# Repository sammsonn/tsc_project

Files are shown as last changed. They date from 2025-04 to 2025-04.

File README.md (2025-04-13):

# Nume: Samson Alexandru-Valentin
# Grupa: 332CC

## 1. Descriere Generala:
Acest repository contine fisierele de design hardware pentru proiectul OpenBook, un e-book reader ieftin si open source, generate in cadrul fazei EVT. Obiectivul acestei faze a fost transformarea specificatiilor de sistem intr-un design hardware functional si integrat mecanic, pregatit pentru fabricarea primelor prototipuri.

## Etapele Initiale ale Dezvoltarii EVT (Rezumat)

Dezvoltarea designului livrat aici a urmat cativa pasi cheie:

1.  **Clarificarea Specificatiilor si Planificarea:** Am inceput prin analiza detaliata a specificatiilor primite de la Arhitectul de Sistem pentru a intelege complet cerintele functionale, de performanta si de cost. Am adresat intrebari pentru clarificarea oricaror ambiguitati si am stabilit un plan de lucru initial. Tot in aceasta etapa am configurat mediul de dezvoltare in Fusion si repository-ul Git.

2.  **Selectia Componentelor si Crearea Librariilor:** Pe baza specificatiilor, am selectat componentele electronice specifice (Part Numbers), acordand o atentie deosebita costului, disponibilitatii pe termen lung si performantei. Pentru fiecare componenta aleasa, am creat sau validat librariile necesare in Fusion 360: simbolul schematic, footprint-ul PCB (conform datasheet) si, unde a fost posibil, modelul 3D asociat. Am inceput compilarea unui Bill of Materials (BOM) preliminar.

3.  **Captura Schematica (Schematic Capture):** Folosind librariile create, am desenat diagrama schematica in Fusion 360. Aceasta reprezinta conexiunile logice dintre toate componentele electronice. Am structurat schema pe module functionale (ex: Alimentare, Procesor, Memorie, Interfata Display, etc.) pentru claritate si am rulat verificari ERC (Electrical Rule Check) pentru a detecta erori de baza.

4.  **Proiectarea PCB (PCB Layout) - Faza Initiala:** Am inceput transpunerea schemei intr-un layout fizic pe placa de circuit imprimat (PCB). Aceasta a inclus definirea conturului placii (conform dimensiunilor impuse de carcasa), definirea structurii straturilor (layer stackup) si plasarea initiala a componentelor critice (conectori, circuite integrate principale, componente cu constrangeri mecanice), tinand cont de fluxul de semnal si constrangerile carcasei.

5.  **Modelare 3D si Integrare Mecanica Preliminara:** in paralel cu layout-ul PCB, am creat modele 3D simplificate, dar dimensional corecte, pentru elementele non-PCB majore (Display E-Ink, Baterie LiPo). Am inceput asamblarea virtuala in Fusion, combinand modelul 3D al PCB-ului (cu componentele plasate), modelele display-ului si bateriei, si modelul 3D al carcasei (primit) pentru a verifica potrivirea generala si a identifica potentiale conflicte de spatiu.

## 2. Diagrama Bloc
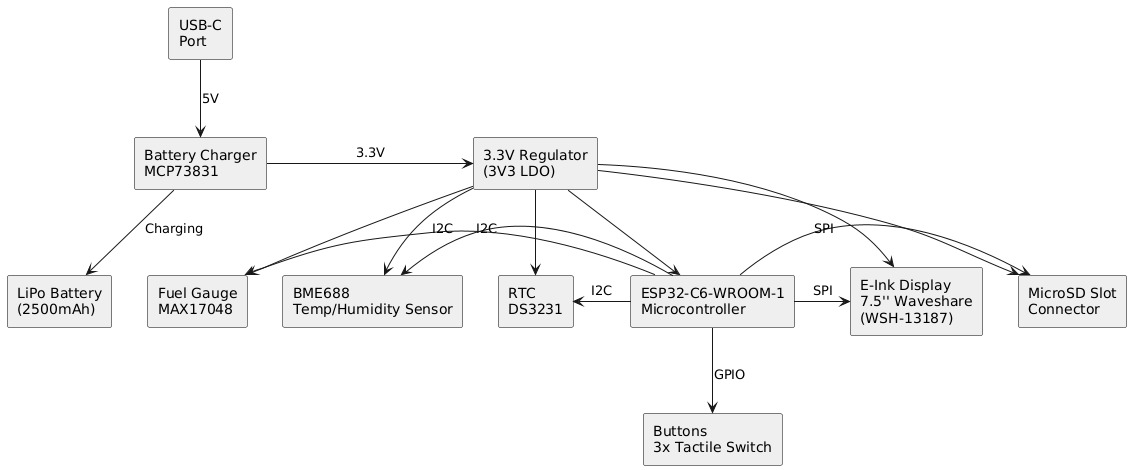
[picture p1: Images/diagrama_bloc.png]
Diagrama


## 3. BOM - Bill of Materials
| Device | Value | Check_Price | Datasheet |
|---|---|---|---|
| ADAFRUIT_LEDCHIP-LED0603 | - | [Link](https://www.snapeda.com/parts/KP-1608SURCK/Kingbright/view-part/?ref=search&t=LED%200603) | [Link](https://www.snapeda.com/parts/KP-1608SURCK/Kingbright/datasheet/) |
| SJ | - | [Link](https://grabcad.com/library/solder-jumpers-1) | [Link](https://grabcad.com/library/solder-jumpers-1) |
| EAGLE-LTSPICE_C | 0.1uF/50V | [Link](https://componentsearchengine.com/part-view/CC0402MRX5R5BB106/YAGEO) | [Link](https://componentsearchengine.com/Datasheets/2/CC0402MRX5R5BB106.pdf) |
| ESP32_WROVER_EAGLE-LTSPICE_R | 0.47 | [Link](https://componentsearchengine.com/part-view/R0402%201%25%20100%20K%20(RC0402FR-07100KL)/YAGEO) | [Link](https://www.yageo.com/upload/media/product/products/datasheet/rchip/PYu-RC_Group_51_RoHS_L_12.pdf) |
| ESP32_WROVER_EAGLE-LTSPICE_R | 100K | [Link](https://componentsearchengine.com/part-view/R0402%201%25%20100%20K%20(RC0402FR-07100KL)/YAGEO) | [Link](https://www.yageo.com/upload/media/product/products/datasheet/rchip/PYu-RC_Group_51_RoHS_L_12.pdf) |
| EAGLE-LTSPICE_C | 100nF | [Link](https://componentsearchengine.com/part-view/CC0402MRX5R5BB106/YAGEO) | [Link](https://componentsearchengine.com/Datasheets/2/CC0402MRX5R5BB106.pdf) |
| RCL_CPOL-EUCT3528 | 100uF TANT | [Link](https://www.snapeda.com/parts/TAJB475K025RNJ/AVX/view-part/?ref=dk&t=capacitor%203528&con_ref=None) | [Link](https://s3.amazonaws.com/snapeda/datasheet/TAJB475K025RNJ_AVX.pdf) |
| ESP32_WROVER_EAGLE-LTSPICE_R | 10K | [Link](https://componentsearchengine.com/part-view/R0402%201%25%20100%20K%20(RC0402FR-07100KL)/YAGEO) | [Link](https://www.yageo.com/upload/media/product/products/datasheet/rchip/PYu-RC_Group_51_RoHS_L_12.pdf) |
| EAGLE-LTSPICE_C | 10uF | [Link](https://componentsearchengine.com/part-view/CC0402MRX5R5BB106/YAGEO) | [Link](https://componentsearchengine.com/Datasheets/2/CC0402MRX5R5BB106.pdf) |
| 112A-TAAR-R03_ATTEND | 112A-TAAR-R03_ATTEND | [Link](https://store.comet.srl.ro/Catalogue/Product/43497/) | [Link](https://store.comet.bg/download-file.php?id=8824) |
| ESP32_WROVER_EAGLE-LTSPICE_R | 15 | [Link](https://componentsearchengine.com/part-view/R0402%201%25%20100%20K%20(RC0402FR-07100KL)/YAGEO) | [Link](https://www.yageo.com/upload/media/product/products/datasheet/rchip/PYu-RC_Group_51_RoHS_L_12.pdf) |
| EAGLE-LTSPICE_C | 1uF | [Link](https://componentsearchengine.com/part-view/CC0402MRX5R5BB106/YAGEO) | [Link](https://componentsearchengine.com/Datasheets/2/CC0402MRX5R5BB106.pdf) |
| EAGLE-LTSPICE_C | 1uF/50V | [Link](https://componentsearchengine.com/part-view/CC0402MRX5R5BB106/YAGEO) | [Link](https://componentsearchengine.com/Datasheets/2/CC0402MRX5R5BB106.pdf) |
| ESP32_WROVER_EAGLE-LTSPICE_R | 2.2 | [Link](https://componentsearchengine.com/part-view/R0402%201%25%20100%20K%20(RC0402FR-07100KL)/YAGEO) | [Link](https://www.yageo.com/upload/media/product/products/datasheet/rchip/PYu-RC_Group_51_RoHS_L_12.pdf) |
| ESP32_WROVER_EAGLE-LTSPICE_R | 200 | [Link](https://componentsearchengine.com/part-view/R0402%201%25%20100%20K%20(RC0402FR-07100KL)/YAGEO) | [Link](https://www.yageo.com/upload/media/product/products/datasheet/rchip/PYu-RC_Group_51_RoHS_L_12.pdf) |
| ESP32_WROVER_SPARKFUN-DISCRETESEMI_MOSFET_PCH-DMG2305UX-7 | 20V/4.2A/52m?/1.4W | [Link](https://componentsearchengine.com/part-view/DMG2305UX-7/Diodes%20Incorporated) | [Link](https://www.diodes.com//assets/Datasheets/DMG2305UX.pdf) |
| ESP32_WROVER_EAGLE-LTSPICE_R | 2K | [Link](https://componentsearchengine.com/part-view/R0402%201%25%20100%20K%20(RC0402FR-07100KL)/YAGEO) | [Link](https://www.yageo.com/upload/media/product/products/datasheet/rchip/PYu-RC_Group_51_RoHS_L_12.pdf) |
| EAGLE-LTSPICE_C | 4.7uF | [Link](https://componentsearchengine.com/part-view/CC0402MRX5R5BB106/YAGEO) | [Link](https://componentsearchengine.com/Datasheets/2/CC0402MRX5R5BB106.pdf) |
| EAGLE-LTSPICE_C | 4.7uF/25V | [Link](https://componentsearchengine.com/part-view/CC0402MRX5R5BB106/YAGEO) | [Link](https://componentsearchengine.com/Datasheets/2/CC0402MRX5R5BB106.pdf) |
| ESP32_WROVER_EAGLE-LTSPICE_R | 5k1 | [Link](https://componentsearchengine.com/part-view/R0402%201%25%20100%20K%20(RC0402FR-07100KL)/YAGEO) | [Link](https://www.yageo.com/upload/media/product/products/datasheet/rchip/PYu-RC_Group_51_RoHS_L_12.pdf) |
| 744043680IND_4828-WE-TPC_WRE | 68uH | [Link](https://ro.mouser.com/ProductDetail/Wurth-Elektronik/744043680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.) | [Link](https://www.we-online.com/components/products/datasheet/744043680.pdf) |
| BD5229G-TR | BD5229G-TR | [Link](https://componentsearchengine.com/part-view/BD5229G-TR/ROHM%20Semiconductor) | [Link](https://datasheet.datasheetarchive.com/originals/distributors/Datasheets_SAMA/f2b9741ef86007909f138d561a359946.pdf) |
| ESP32_WROVER_BME680_BME680 | BME688 | [Link](https://www.snapeda.com/parts/BME680/Bosch/view-part/?welcome=home) | [Link](https://www.snapeda.com/parts/BME680/Bosch%20Sensortec/datasheet/) |
| BUTTON_CUSYOMV1V2 | BUTTON_CUSYOMV1V2 | [Link](https://industry.panasonic.com/global/en/products/control/switch/light-touch/number/evqpuj02k) | [Link](https://industry.panasonic.com/global/en/downloads?tab=catalog&small_g_cd=203&part_no=EVQPUJ02K) |
| CPH3225A | CPH3225A | [Link](https://www.snapeda.com/parts/CPH3225A/Seiko+Instruments/view-part/?ref=eda) | [Link](https://www.snapeda.com/parts/CPH3225A/Seiko+Instruments/view-part/?ref=eda ) |
| DS3231SN# | DS3231SN# | [Link](https://www.snapeda.com/parts/DS3231SN%23/Analog+Devices/view-part/?ref=eda) | [Link](https://www.snapeda.com/parts/DS3231SN%23/Analog+Devices/view-part/?ref=eda) |
| ESP32-C6-WROOM-1-N8 | ESP32-C6-WROOM-1-N8 | [Link](https://www.snapeda.com/parts/ESP32-C6-WROOM-1-N8/Espressif+Systems/view-part/?ref=eda) | [Link](https://www.snapeda.com/parts/ESP32-C6-WROOM-1-N8/Espressif+Systems/view-part/?ref=eda) |
| ESP32C6_VARISTORCN1812 | ESP32C6_VARISTORCN1812 | [Link](https://www.mouser.co.uk/ProductDetail/EPCOS-TDK/B72520T0350K062?qs=dEfas%2FXlABIszF52uu7vrg%3D%3D) | [Link](https://www.tdk-electronics.tdk.com/inf/75/db/CTVS_14/Surge_protection_series.pdf) |
| ESP32_WROVER_SPARKFUN-IC-POWER_MCP73831 | ESP32_WROVER_SPARKFUN-IC-POWER_MCP73831 | [Link](https://ro.mouser.com/ProductDetail/Microchip-Technology/MCP73831T-2ACI-OT?qs=yUQqVecv4qvbBQBGbHx0Mw%3D%3D) | [Link](https://ro.mouser.com/datasheet/2/268/MCP73831_Family_Data_Sheet_DS20001984H-3441711.pdf) |
| FH34SRJ-24S-0.5SH_99_ | FH34SRJ-24S-0.5SH_99_ | [Link](https://componentsearchengine.com/part-view/FH34SRJ-24S-0.5SH(99)/Hirose) | [Link](https://www.hirose.com/en/product/document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) |
| MAX17048G+T10 | MAX17048G+T10 | [Link](https://www.snapeda.com/parts/MAX17048G+T10/Analog+Devices/view-part/?ref=eda) | [Link](https://www.snapeda.com/parts/MAX17048G+T10/Analog+Devices/view-part/?ref=eda) |
| MBR0530. | MBR0530. | [Link](https://www.snapeda.com/parts/MBR0530/Onsemi/view-part/?ref=eda) | [Link](https://www.snapeda.com/parts/MBR0530/ON%20Semiconductor/datasheet/) |
| PGB1010603MR. | PGB1010603MR. | [Link](https://www.snapeda.com/parts/PGB1010603MR/Littelfuse/view-part/?ref=eda) | [Link](https://www.snapeda.com/parts/PGB1010603MR/Littelfuse%20Inc./datasheet/) |
| QWIIC_CONNECTORJS-1MM | QWIIC_RIGHT_ANGLE | [Link](https://www.digikey.lt/en/models/926710 ) | [Link](https://www.digikey.lt/en/models/926710) |
| SAMACSYS_PARTS_USB4110-GF-A | SAMACSYS_PARTS_USB4110-GF-A | [Link](https://componentsearchengine.com/part-view/USB4110-GF-A/GCT%20(GLOBAL%20CONNECTOR%20TECHNOLOGY)) | [Link](https://gct.co/files/drawings/usb4110.pdf) |
| ESP32_WROVER_AVX---SD0805S020S1R0_AVX_SD0805S020S1R0_0_0AVX_SD0805S020S1R0_0_0 | SD0805S020S1R0 | [Link](https://ro.mouser.com/ProductDetail/KYOCERA-AVX/SD0805S020S1R0?qs=jCA%252BPfw4LHbpkAoSnwrdjw%3D%3D) | [Link](http://datasheets.avx.com/schottky.pdf) |
| SI1308EDL-T1-GE3 | SI1308EDL-T1-GE3 | [Link](https://www.snapeda.com/parts/SI1308EDL-T1-GE3/Vishay+Siliconix/view-part/?ref=eda) | [Link](https://www.snapeda.com/parts/SI1308EDL-T1-GE3/Vishay+Siliconix/view-part/?ref=eda) |
| TPV1 | TPV1 | Custom made | - |
| USBLC6-2SC6Y | USBLC6-2SC6Y | [Link](https://www.snapeda.com/parts/USBLC6-2SC6Y/STMicroelectronics/view-part/?ref=eda) | [Link](https://www.snapeda.com/parts/USBLC6-2SC6Y/STMicroelectronics/view-part/?ref=eda) |
| W25Q512JVEIQ | W25Q512JVEIQ | [Link](https://www.snapeda.com/parts/W25Q512JVEIQ/Winbond+Electronics/view-part/?ref=eda) | [Link](https://www.snapeda.com/parts/W25Q512JVEIQ/Winbond+Electronics/view-part/?ref=eda) |
| XC6220A331MR-G | XC6220A331MR-G | [Link](https://componentsearchengine.com/part-view/XC6220A331MR-G/Torex) | [Link](https://product.torexsemi.com/system/files/series/xc6220.pdf) |

## 4. Arhitectura Hardware

Mai jos sunt detaliate componentele hardware esentiale si rolul lor in functionarea dispozitivului:

| Nr. | Componenta Principala |
|-----|---|
| 1 | Microcontroller – ESP32-C6-WROOM-1 |
| 2 | Ecran E-Ink – Waveshare WSH-13187, 7.5”  |
| 3 | Senzor Ambiental – Bosch BME688 |
| 4 | Sistem de Alimentare si Baterie |
| 5 | Butoane de Control – 3x Tactile Switch |
| 6 | Conector USB-C |
| 7 | Port Extensie Qwiic / STEMMA QT (I2C) |
| 8 | Soclu MicroSD – Attend 112A-TAAR-R03 |
| 9 | Ceas Timp Real (RTC) – DS3231 |

### 4.1. Unitatea Centrala – Microcontroller ESP32-C6-WROOM-1

-   **Unitate de Procesare:** RISC-V 32-bit, frecventa 160MHz
-   **Memorie:** 512KB SRAM intern + 8MB memorie flash extern (model W25Q512JVEIQ)
-   **Optiuni de Comunicare:** Wi-Fi 6 (standard 802.11ax), Bluetooth 5 LE, interfata USB 2.0 Full-Speed
-   **Interfete Disponibile:** SPI, I2C, UART, multiple porturi GPIO
-   **Consum Energetic:** Sub 50µA in modul deep sleep; diverse moduri de consum redus implementate
-   **Functii de Securitate:** Include secure boot, criptare pentru memoria flash si accelerare hardware pentru criptografie

### 4.2. Afisajul Electronic – Ecran E-Ink Waveshare WSH-13187, 7.5”

-   **Rezolutie:** 800x480 pixeli, imagine monocroma
-   **Modalitate de Conectare:** Interfata SPI (4 fire) plus linii de control CS, DC, RST, BUSY
-   **Consum Energetic:** Aproximativ 15–25mA in timpul actualizarii imaginii; consum neglijabil in stare statica
-   **Motivul alegerii:** Consum de energie neglijabil cand imaginea este statica, ideal pentru un e-reader

### 4.3. Senzorul Ambiental Integrat – Bosch BME688

-   **Parametri Masurati:** Temperatura, Umiditate relativa, Presiune atmosferica, Indice al Calitatii Aerului (estimare eCO2, TVOC)
-   **Acuratete:** ±1°C pentru temperatura, ±3% pentru umiditate, ±1 hPa pentru presiune
-   **Modalitate de Conectare:** Interfata I2C (operare la 400kHz)
-   **Consum Energetic:** 2.1µA in standby, maxim 3.6mA in timpul masuratorilor active
-   **Motivul alegerii:** Solutie compacta multi-senzor, potrivita pentru monitorizarea conditiilor ambientale

### 4.4. Sistemul de Alimentare si Gestionarea Energiei

-   **Sursa de Energie:** Acumulator Li-Po de 3.7V cu o capacitate de 2500mAh
-   **Monitorizare Baterie:** Circuit integrat MAX17048 (comunica prin I2C)
-   **Circuit de Incarcare:** MCP73831 – permite incarcarea cu 5V/1A via portul USB-C
-   **Regulator de Tensiune:** LDO ce furnizeaza o tensiune stabila de 3.3V pentru intregul circuit
-   **Consum Total Estimativ:**
    -   In mod activ: intre 100 si 150mA
    -   In mod deep sleep: sub 50µA

### 4.5. Interfata cu Utilizatorul – 3x Butoane Tactile

-   **Model Buton:** Panasonic EVQ-Q2A03W
-   **Conectare Electrica:** Legate la pini GPIO, cu circuit de debounce hardware (filtru RC)
-   **Functionalitati Asignate:** Navigare prin meniuri, avansare/revenire pagina, confirmare actiuni

### 4.6. Conectorul USB-C

-   **Functionalitati Principale:** Incarcarea bateriei si transferul de date (conform standardului USB 2.0)
-   **Masuri de Protectie:** Protectie ESD integrata si terminatii conforme standardului
-   **Posibilitati Suplimentare:** Actualizari software OTA (Over-The-Air) via Wi-Fi sau actualizare firmware prin conexiune USB

### 4.7. Portul de Extensie Qwiic / STEMMA QT (I2C)

-   **Configuratie Pini:** VCC (Alimentare), GND (Masa), SDA (Date I2C), SCL (Ceas I2C)
-   **Scop/Beneficii:** Permite conectarea rapida a modulelor si senzorilor externi compatibili I2C

### 4.8. Soclul pentru Card MicroSD – Attend 112A-TAAR-R03

-   **Rol Principal:** Ofera spatiu de stocare extern (pentru carti electronice, fisiere jurnal, firmware etc.)
-   **Modalitate de Conectare:** Interfata SPI

### 4.9. Ceasul Timp Real (RTC) – DS3231

-   **Acuratete:** Deviatie maxima de ±2 parti per milion (ppm)
-   **Modalitate de Conectare:** Interfata I2C
-   **Alimentare de Backup:** Asigurata de un supercapacitor

---

### Protocoale de Comunicare si Interfete Utilizate

| Protocol/Interfata | Componente Conectate |
|---|---|
| **SPI** | Ecran E-Paper, Memorie Flash externa, Card SD (SPI) |
| **I2C** | Senzor BME688, Fuel Gauge MAX17048, RTC DS3231, Port Qwiic/Stemma |
| **USB** | Incarcare si comunicatie de date via USB-C |
| **GPIO** | Butoane, Linii control afisaj, Activare incarcare |

---

### Profil de Consum Energetic (Estimari)

| Stare/Componenta | Consum Estimativ |
|---|---|
| ESP32-C6 (mod activ) | 80–100mA |
| Actualizare E-Paper | 15–25mA |
| Senzor BME688 (activ)  | 3.6mA |
| Fuel Gauge MAX17048 | ~50µA |
| RTC DS3231 | 3.5mA / 1µA backup |
| Deep Sleep (Total) | <50–100µA |

---

### Specificatii Fizice si Constructive

-   **Marimi Fizice:** 175 x 114 x 10 mm
-   **Masa Dispozitivului:** Aproximativ 250g
-   **Material Carcasa:** ABS sau policarbonat, cu design ergonomic
-   **Montare Afisaj:** Integrat intr-un decupaj specific al carcasei
-   **Detalii de Fabricatie:** PCB cu 2 straturi, finisaj ENIG, carcasa obtinuta prin injectie de plastic

## 5. Pini utilizati pe ESP32-C6 si justificare

| Pin ESP32-C6 | Componenta / Semnal | Justificare |
|---|---|---|
| GPIO1 | I2C SDA (BME688, MAX17048, DS3231, Qwiic) | Linie partajata I2C - economiseste pini si permite extinderea usoara a sistemului |
| GPIO2 | I2C SCL (BME688, MAX17048, DS3231, Qwiic) | Semnal de ceas I2C pentru toti senzorii si portul de extensie Qwiic |
| GPIO5 | SPI MISO (E-Paper, Flash extern) | Linie comuna de intrare date (Master In Slave Out) pentru SPI |
| GPIO6 | SPI MOSI (E-Paper, Flash extern) | Linie comuna de iesire date (Master Out Slave In) pentru SPI |
| GPIO7 | SPI CLK | Semnal de ceas (Clock) pentru magistrala SPI |
| GPIO8 | E-Paper CS | Selecteaza (Chip Select) ecranul E-Paper pe magistrala SPI |
| GPIO9 | E-Paper DC (Data/Command) | Comuta intre modul de comanda si modul de date pentru E-Paper |
| GPIO10 | E-Paper RST | Linie de reset hardware pentru ecranul E-Paper |
| GPIO11 | E-Paper BUSY | Indica starea display-ului (ocupat/liber) |
| GPIO12 | Button #1 | Intrare digitala pentru butonul de navigare (ex: pagina inainte) |
| GPIO13 | Button #2 | Intrare digitala pentru butonul de navigare (ex: pagina inapoi) |
| GPIO14 | Button #3 | Intrare digitala pentru butonul de selectie sau optiuni |
| GPIO15 | MAX17048 ALERT (optional) | Pin optional pentru alerta de nivel scazut al bateriei de la MAX17048 |
| GPIO16 | USB D+ (intern la USB PHY) | Linie de date pozitiva USB 2.0 (pin dedicat pe ESP32-C6) |
| GPIO17 | USB D- (intern la USB PHY) | Linie de date negativa USB 2.0 (pin dedicat pe ESP32-C6) |
| GPIO18 | LED Status (optional) | Iesire pentru un LED de stare (ex: activitate Wi-Fi, incarcare, etc.) |
| GPIO19 | SD Card CS | Selectare (Chip Select) pentru cardul microSD pe magistrala SPI |
| GPIO20 | SD Card MISO | Linie de citire date (Master In Slave Out) de pe cardul microSD |
| GPIO21 | SD Card MOSI | Linie de scriere date (Master Out Slave In) pe cardul microSD |
| GPIO4 | SD Card CLK | Semnal de ceas (Clock) pentru cardul microSD (SPI) |

## 6. Probleme Intampinate
1) In etapa de modelare 3D, a aparut o dificultate majora: modelele 3D pentru rezistente si condensatoare nu se actualizau automat in proiectul PCB la utilizarea functiei 'Replace Package'. Solutia a fost adaugarea manuala a modelelor 3D personalizate pentru fiecare dintre aceste componente.

2) Dimensiunea pad-urilor pentru bobina si conectorul USB, asa cum erau definite initial in footprint, s-a dovedit a fi insuficienta pentru grosimea terminalelor/pinilor. A fost necesara marirea manuala a acestor pad-uri in footprint pentru a facilita procesul de lipire.

## 7. Observatii
Un proiect cu un volum de munca foarte mare, care in opinia mea depaseste valoarea de 2 puncte din nota finala. Timp estimat de lucru: ~80 ore.

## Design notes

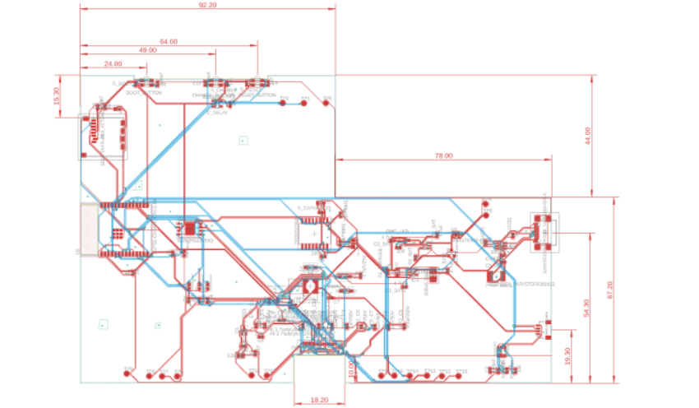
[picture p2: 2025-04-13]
Images/PCB_Routing.png

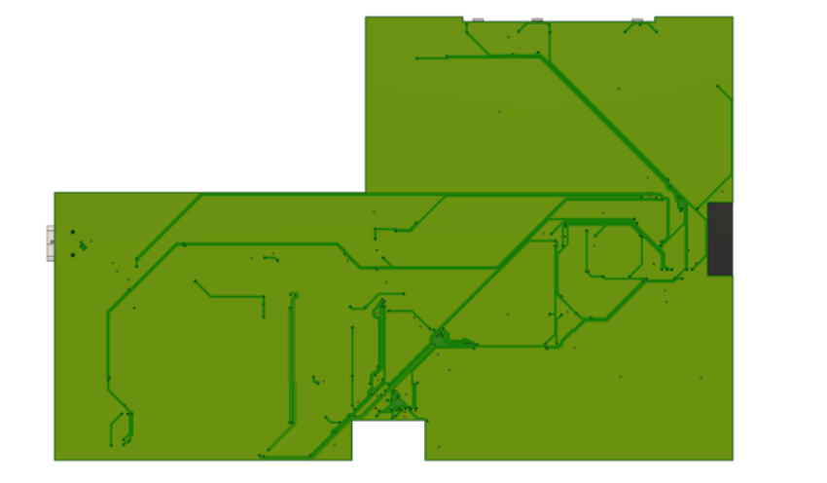
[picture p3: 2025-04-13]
Images/PCB_Bottom.png

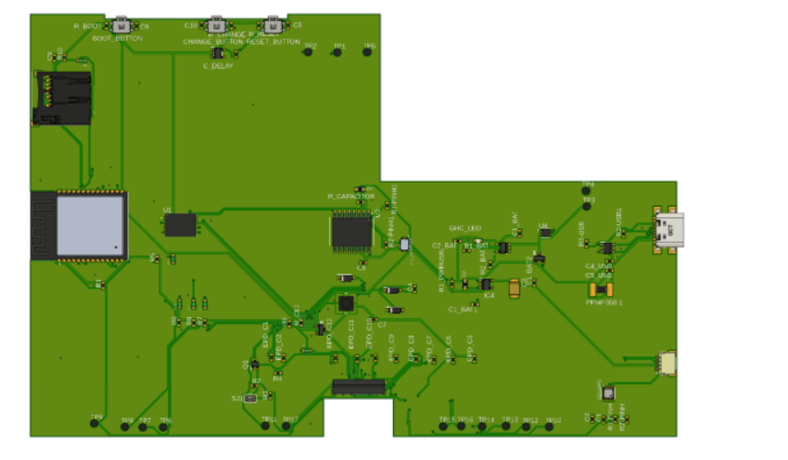
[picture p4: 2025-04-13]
Images/PCB_Top.png

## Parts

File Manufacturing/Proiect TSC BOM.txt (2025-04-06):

Partlist exported from Fusion Hub: Samson   Project: Admin Project  Board: Proiect TSC v26 at 06.04.2025 23:14

Qty Value                                                                          Device                                                                         Package                                                Parts                                                                                                   Description                                                                                                                                                                                                                                                                                                                                                                                                                                                                                          ARROW_PART_NUMBER ARROW_PRICE-STOCK AVAILABILITY CENTROID_NOT_SPECIFIED CHECK_PRICES                                                                           COPYRIGHT                                                DATASHEET                              DESCRIPTION                                                                                        DIGIKEY_DESCRIPTION                                                                                                                                                                                                      DIGIKEY_PART_NUMBER                           HEIGHT                                                                                LEAD_FREE                                                          MANUFACTURER_NAME                 MANUFACTURER_PART_NUMBER MF                  MFR_NAME          MOUSER_PART_NUMBER    MOUSER_PRICE-STOCK                                                                                        MOUSER_TESTING_PART_NUMBER MOUSER_TESTING_PRICE-STOCK MP                                                                                                                  MPN                                                                                                  PACKAGE                     POPULARITY          PREFIX PRICE                        PROD_ID    PURCHASE-URL                                                                                                                                ROHS SNAPEDA_LINK                                                                       SPICEMODEL                                                                                                                                      SPICEPREFIX TEMPERATURE_RANGE_HIGH                                                                  TEMPERATURE_RANGE_LOW TP_SIGNAL_NAME VALUE             
1                                                                                  ADAFRUIT_LEDCHIP-LED0603                                                       ADAFRUIT_CHIP-LED0603                                  GHC_LED                                                                                                 LED                                                                                                                                                                                                                                                                                                                                                                                                                                                                                                                                                                                                                                                                                                                                                                                                                                                                                                                                                                                                                                                                                                                                                                                                                                                                                                                                                                                                                                                                                                                                                                                                                                                                                                                                                                                                                                                                                                                                                                                                                                                                                                                                                                                                                                                                                                                                                                                                                                                                  
1                                                                                  ESP32_WROVER_EAGLE-LTSPICE_RR0402                                              ESP32_WROVER_EAGLE-LTSPICE_R0402                       R_CAPACITOR                                                                                             RESISTOR, European symbol                                                                                                                                                                                                                                                                                                                                                                                                                                                                                                                                                                                                                                                                                                                                                                                                                                                                                                                                                                                                                                                                                                                                                                                                                                                                                                                                                                                                                                                                                                                                                                                                                                                                                                                                                                                                                                                                                                                                                                                                                                                                                                                                 NONE                                                                                                                                            R                                                                                                                                                          
1                                                                                  SJ                                                                             SJ                                                     SJ1                                                                                                     SMD solder JUMPER                                                                                                                                                                                                                                                                                                                                                                                                                                                                                                                                                                                                                                                                                                                                                                                                                                                                                                                                                                                                                                                                                                                                                                                                                                                                                                                                                                                                                                                                                                                                                                                                                                                                                                                                                                                                                                  3                                                                                                                                                                                                                                                                                                                                                                                                                                                                                                                                                                                                                 
1   0.1uF/50V                                                                      ESP32_WROVER_EAGLE-LTSPICE_CC0402                                              ESP32_WROVER_EAGLE-LTSPICE_C0402                       EPD_C5                                                                                                  CAPACITOR, European symbol                                                                                                                                                                                                                                                                                                                                                                                                                                                                                                                                                                                                                                                                                                                                                                                                                                                                                                                                                                                                                                                                                                                                                                                                                                                                                                                                                                                                                                                                                                                                                                                                                                                                                                                                                                                                                                                                                                                                                                                                                                                                                                                                NONE                                                                                                                                            C                                                                                                                                                          
1   0.47                                                                           ESP32_WROVER_EAGLE-LTSPICE_RR0402                                              ESP32_WROVER_EAGLE-LTSPICE_R0402                       R3                                                                                                      RESISTOR, European symbol                                                                                                                                                                                                                                                                                                                                                                                                                                                                                                                                                                                                                                                                                                                                                                                                                                                                                                                                                                                                                                                                                                                                                                                                                                                                                                                                                                                                                                                                                                                                                                                                                                                                                                                                                                                                                                                                                                                                                                                                                                                                                                                                 NONE                                                                                                                                            R                                                                                                                                                          
1   100k                                                                           ESP32_WROVER_EAGLE-LTSPICE_RR0402                                              ESP32_WROVER_EAGLE-LTSPICE_R0402                       R1_PWRUSB                                                                                               RESISTOR, European symbol                                                                                                                                                                                                                                                                                                                                                                                                                                                                                                                                                                                                                                                                                                                                                                                                                                                                                                                                                                                                                                                                                                                                                                                                                                                                                                                                                                                                                                                                                                                                                                                                                                                                                                                                                                                                                                                                                                                                                                                                                                                                                                                                 NONE                                                                                                                                            R                                                                                                                                                          
8   100nF                                                                          ESP32_WROVER_EAGLE-LTSPICE_CC0402                                              ESP32_WROVER_EAGLE-LTSPICE_C0402                       C1, C2, C4_USB, C6, C8, C9, C10, C_DELAY                                                                CAPACITOR, European symbol                                                                                                                                                                                                                                                                                                                                                                                                                                                                                                                                                                                                                                                                                                                                                                                                                                                                                                                                                                                                                                                                                                                                                                                                                                                                                                                                                                                                                                                                                                                                                                                                                                                                                                                                                                                                                                                                                                                                                                                                                                                                                                                                NONE                                                                                                                                            C                                                                                                                                                          
1   100uF TANT                                                                     RCL_CPOL-EUCT3528                                                              RCL_CT3528                                             C3                                                                                                      POLARIZED CAPACITOR, European symbol                                                                                                                                                                                                                                                                                                                                                                                                                                                                                                                                                                                                                                                                                                                                                                                                                                                                                                                                                                                                                                                                                                                                                                                                                                                                                                                                                                                                                                                                                                                                                                                                                                                                                                                                                                                                               0                                                                                                                                                                                                                                                                                                                                                                                                                                                      C                                                                                                                                                          
16  10k                                                                            ESP32_WROVER_EAGLE-LTSPICE_RR0402                                              ESP32_WROVER_EAGLE-LTSPICE_R0402                       R1, R1-PINH, R1-PINH1, R2-PINH, R2-PINH1, R4, R5, R6, R7, R8, R9, R10, R_BOOT, R_CHANGE, R_CL1, R_RESET RESISTOR, European symbol                                                                                                                                                                                                                                                                                                                                                                                                                                                                                                                                                                                                                                                                                                                                                                                                                                                                                                                                                                                                                                                                                                                                                                                                                                                                                                                                                                                                                                                                                                                                                                                                                                                                                                                                                                                                                                                                                                                                                                                                                                                                                                                                 NONE                                                                                                                                            R                                                                                                                                                          
1   10uF                                                                           ESP32_WROVER_EAGLE-LTSPICE_CC0402                                              ESP32_WROVER_EAGLE-LTSPICE_C0402                       C7                                                                                                      CAPACITOR, European symbol                                                                                                                                                                                                                                                                                                                                                                                                                                                                                                                                                                                                                                                                                                                                                                                                                                                                                                                                                                                                                                                                                                                                                                                                                                                                                                                                                                                                                                                                                                                                                                                                                                                                                                                                                                                                                                                                                                                                                                                                                                                                                                                                NONE                                                                                                                                            C
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

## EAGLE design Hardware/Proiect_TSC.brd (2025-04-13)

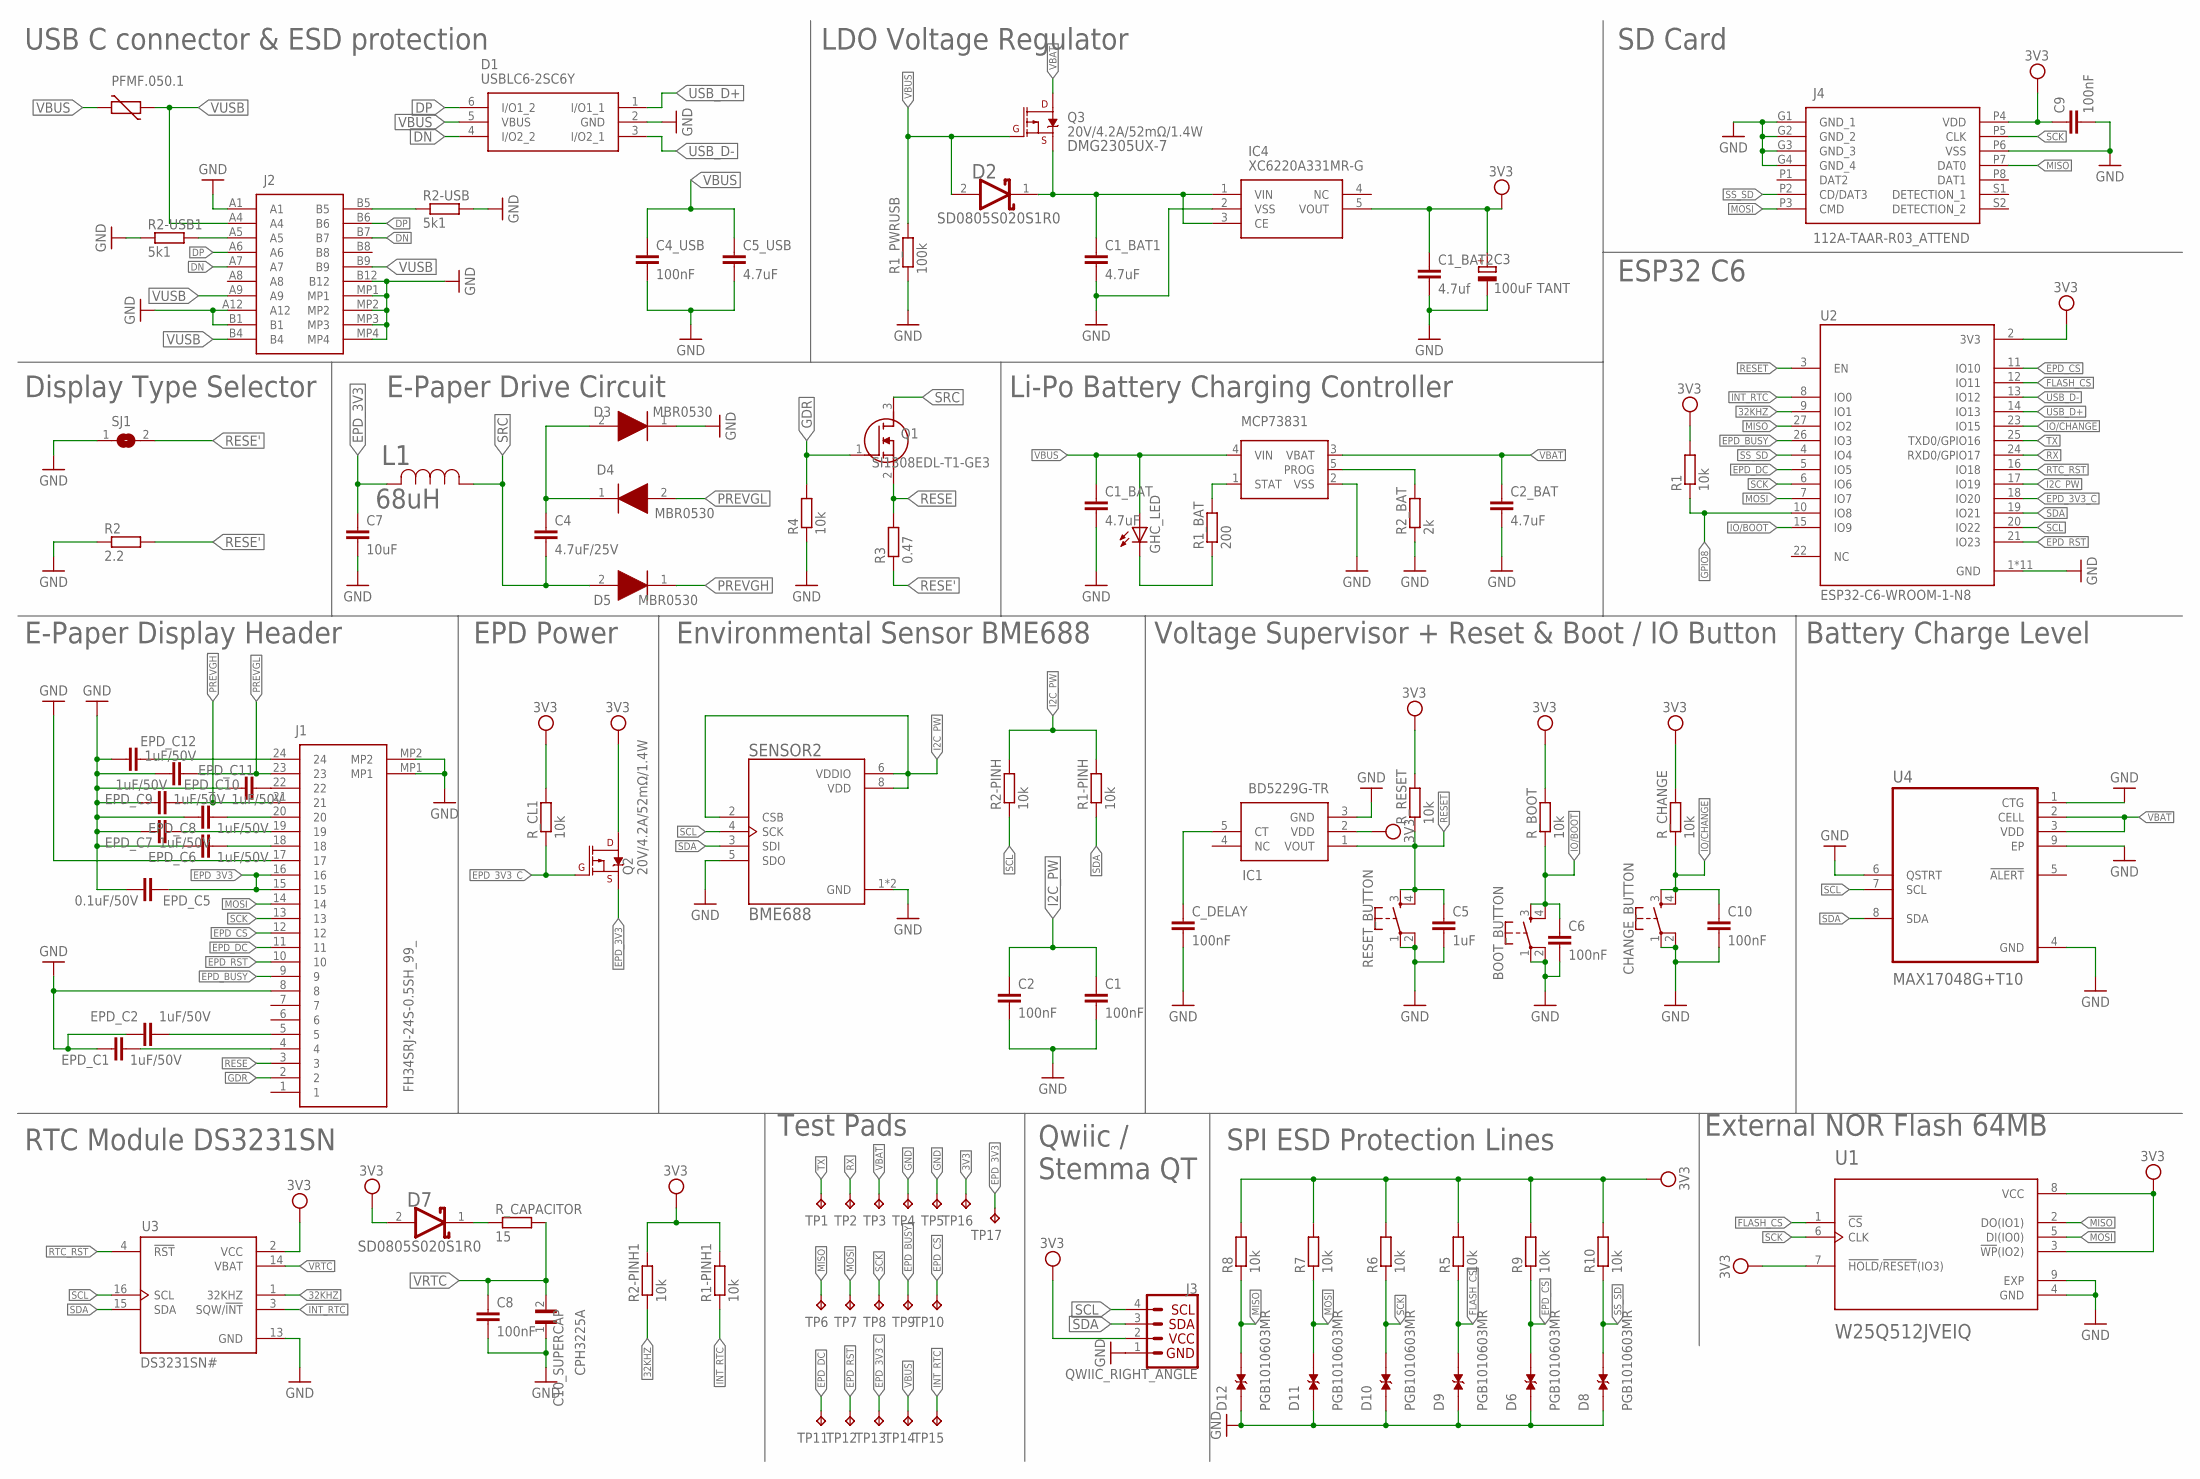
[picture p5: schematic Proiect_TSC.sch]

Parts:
BOOT_BUTTON: BUTTON_CUSYOMV1; MYBUTTON
C1, C2, C4_USB, C6, C8, C9, C10: 100nF; ESP32_WROVER_EAGLE-LTSPICE_C0402
C1_BAT, C1_BAT1, C2_BAT: 4.7uF; EAGLE-LTSPICE_C0402
C1_BAT2: 4.7uf; EAGLE-LTSPICE_C0402
C3: 100uF TANT; RCL_CT3528
C4: 4.7uF/25V; ESP32_WROVER_EAGLE-LTSPICE_C0402
C5: 1uF; ESP32_WROVER_EAGLE-LTSPICE_C0402
C5_USB: 4.7uF; ESP32_WROVER_EAGLE-LTSPICE_C0402
C7: 10uF; ESP32_WROVER_EAGLE-LTSPICE_C0402
C10_SUPERCAP: CPH3225A; CAPCP3225X100N
CHANGE_BUTTON: BUTTON_CUSYOMV1; MYBUTTON
C_DELAY: 100nF; ESP32_WROVER_EAGLE-LTSPICE_C0402
D1: USBLC6-2SC6Y; SOT95P280X145-6N
D2: SD0805S020S1R0; ESP32_WROVER_AVX---SD0805S020S1R0_AVX_SD0805S020S1R0_0
D3, D4, D5: MBR0530; SOD3716X135N
D6, D8, D9, D10, D11, D12: PGB1010603MR; DIOC1608X36N
D7: ESP32_WROVER_AVX---SD0805S020S1R0_AVX_SD0805S020S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; ESP32_WROVER_AVX---SD0805S020S1R0_AVX_SD0805S020S1R0_0
EPD_C1, EPD_C2, EPD_C6, EPD_C7, EPD_C8, EPD_C9, EPD_C10, EPD_C11, EPD_C12: 1uF/50V; ESP32_WROVER_EAGLE-LTSPICE_C0402
EPD_C5: 0.1uF/50V; ESP32_WROVER_EAGLE-LTSPICE_C0402
GHC_LED: ADAFRUIT_LEDCHIP-LED0603; ADAFRUIT_CHIP-LED0603
IC1: BD5229G-TR; SOT95P280X125-5N
IC4: XC6220A331MR-G; SOT95P280X120-5N
J1: FH34SRJ-24S-0.5SH_99_; FH34SRJ24S05SH99
J2: SAMACSYS_PARTS_USB4110-GF-A; SAMACSYS_PARTS_USB4110GFA
J3: QWIIC_RIGHT_ANGLE; JST04_1MM_RA
J4: 112A-TAAR-R03_ATTEND; 112ATAARR03ATTEND
L1: 68uH; IND_4828-WE-TPC_WRE
PFMF.050.1: ESP32C6_VARISTORCN1812; ESP32C6_VARISTOR_CT/CN1812
Q1: SI1308EDL-T1-GE3; SOT65P210X110-3N
Q2, Q3: 20V/4.2A/52mΩ/1.4W; ESP32_WROVER_SPARKFUN-DISCRETESEMI_SOT23-3
R1, R1-PINH, R1-PINH1, R2-PINH, R2-PINH1, R4, R5, R6, R7, R8, R9, R10: 10k; ESP32_WROVER_EAGLE-LTSPICE_R0402
R1_BAT: 200; ESP32_WROVER_EAGLE-LTSPICE_R0402
R1_PWRUSB: 100k; ESP32_WROVER_EAGLE-LTSPICE_R0402
R2: 2.2; ESP32_WROVER_EAGLE-LTSPICE_R0402
R2-USB, R2-USB1: 5k1; ESP32_WROVER_EAGLE-LTSPICE_R0402
R2_BAT: 2k; ESP32_WROVER_EAGLE-LTSPICE_R0402
R3: 0.47; ESP32_WROVER_EAGLE-LTSPICE_R0402
RESET_BUTTON: BUTTON_CUSYOMV1; MYBUTTON
R_BOOT: 10k; ESP32_WROVER_EAGLE-LTSPICE_R0402
R_CAPACITOR: 15; ESP32_WROVER_EAGLE-LTSPICE_R0402
R_CHANGE: 10k; ESP32_WROVER_EAGLE-LTSPICE_R0402
R_CL1: 10k; ESP32_WROVER_EAGLE-LTSPICE_R0402
R_RESET: 10k; ESP32_WROVER_EAGLE-LTSPICE_R0402
SENSOR2: BME688; ESP32_WROVER_BME680_PSON80P300X300X100-8N
SJ1: SJ
TP1, TP2, TP3, TP4, TP5, TP6, TP7, TP8, TP9, TP10, TP11, TP12, TP13, TP14, TP15, TP16, TP17: TPTP20R; TP20R
U: MCP73831; ESP32_WROVER_SPARKFUN-IC-POWER_SOT23-5
U1: W25Q512JVEIQ; SON127P600X800X80-9N
U2: ESP32-C6-WROOM-1-N8; XCVR_ESP32-C6-WROOM-1-N8
U3: DS3231SN#; SOIC127P1032X265-16N
U4: MAX17048G+T10; SON50P200X200X80-9N

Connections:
3V3: C1_BAT2.1, C3.+, C9.1, D7.2 (ANODE), IC1.2 (VDD), IC4.5 (VOUT), J3.2, J4.P4 (VDD), Q2.3 (D), R1.2, R1-PINH1.2, R2-PINH1.2, R5.2, R6.2, R7.2, R8.2, R9.2, R10.2, R_BOOT.2, R_CHANGE.2, R_CL1.2, R_RESET.2, TP16.TP, U1.3 (!WP!(IO2)), U1.7 (!HOLD!/!RESET!(IO3)), U1.8 (VCC), U2.2 (3V3), U3.2 (VCC)
32KHZ: R2-PINH1.1, U2.9 (IO1), U3.1 (32KHZ)
DN: D1.4 (I/O2_2), J2.A7, J2.B7
DP: D1.6 (I/O1_2), J2.A6, J2.B6
EPD_3V3: C7.1, EPD_C5.2, J1.15, J1.16, L1.2, Q2.2 (S), TP17.TP
EPD_3V3_C: Q2.1 (G), R_CL1.1, TP13.TP, U2.18 (IO20)
EPD_BUSY: J1.9, TP9.TP, U2.26 (IO3)
EPD_CS: D6.2, J1.12, R9.1, TP10.TP, U2.11 (IO10)
EPD_DC: J1.11, TP11.TP, U2.5 (IO5)
EPD_RST: J1.10, TP12.TP, U2.21 (IO23)
FLASH_CS: D9.2, R5.1, U1.1 (!CS), U2.12 (IO11)
GDR: J1.2, Q1.1 (G), R4.2
GND: BOOT_BUTTON.1, BOOT_BUTTON.2, C1.2, C1_BAT.2, C1_BAT1.2, C1_BAT2.2, C2.2, C2_BAT.2, C3.-, C4_USB.2, C5.2, C5_USB.2, C6.2, C7.2, C8.2, C9.2, C10.2, C10_SUPERCAP.1, CHANGE_BUTTON.1, CHANGE_BUTTON.2, C_DELAY.2, D1.2 (GND), D3.1 (K), D6.1, D8.1, D9.1, D10.1, D11.1, D12.1, EPD_C1.1, EPD_C2.1, EPD_C5.1, EPD_C6.1, EPD_C7.1, EPD_C8.1, EPD_C9.1, EPD_C10.1, EPD_C11.1, EPD_C12.1, IC1.3 (GND), IC4.2 (VSS), J1.8, J1.17, J1.MP1, J1.MP2, J2.A1, J2.A12, J2.B1, J2.B12, J2.MP1, J2.MP2, J2.MP3, J2.MP4, J3.1, J4.G1 (GND_1), J4.G2 (GND_2), J4.G3 (GND_3), J4.G4 (GND_4), J4.P6 (VSS), R1_PWRUSB.1, R2.1, R2-USB.2, R2-USB1.1, R2_BAT.1, R4.1, RESET_BUTTON.1, RESET_BUTTON.2, SENSOR2.1 (GND), SENSOR2.5 (SDO), SENSOR2.7 (GND), SJ1.1, TP4.TP, TP5.TP, U.2 (VSS), U1.4 (GND), U1.9 (EXP), U2.1 (GND), U2.28 (GND), U2.29_1 (GND), U2.29_2 (GND), U2.29_3 (GND), U2.29_4 (GND), U2.29_5 (GND), U2.29_6 (GND), U2.29_7 (GND), U2.29_8 (GND), U2.29_9 (GND), U3.13 (GND), U4.1 (CTG), U4.4 (GND), U4.6 (QSTRT), U4.9 (EP)
GPIO8: R1.1, U2.10 (IO8)
I2C_PW: C1.1, C2.1, R1-PINH.2, R2-PINH.2, SENSOR2.2 (CSB), SENSOR2.6 (VDDIO), SENSOR2.8 (VDD), U2.17 (IO19)
INT_RTC: R1-PINH1.1, TP15.TP, U2.8 (IO0), U3.3 (SQW/!INT)
IO/BOOT: BOOT_BUTTON.3, BOOT_BUTTON.4, C6.1, R_BOOT.1, U2.15 (IO9)
IO/CHANGE: C10.1, CHANGE_BUTTON.3, CHANGE_BUTTON.4, R_CHANGE.1, U2.23 (IO15)
MISO: D12.2, J4.P7 (DAT0), R8.1, TP6.TP, U1.2 (DO(IO1)), U2.27 (IO2)
MOSI: D11.2, J1.14, J4.P3 (CMD), R7.1, TP7.TP, U1.5 (DI(IO0)), U2.7 (IO7)
unnamed: J2.A5, R2-USB1.2
unnamed: J2.B5, R2-USB.1
unnamed: C4.1, D3.2 (A), D4.1 (K)
unnamed: EPD_C2.2, J1.5
unnamed: EPD_C1.2, J1.4
unnamed: EPD_C6.2, J1.18
unnamed: EPD_C8.2, J1.20
unnamed: EPD_C7.2, J1.19
unnamed: EPD_C12.2, J1.24
unnamed: EPD_C10.2, J1.22
unnamed: D7.1 (CATHODE), R_CAPACITOR.1
unnamed: C1_BAT1.1, D2.1 (CATHODE), IC4.1 (VIN), IC4.3 (CE), Q3.2 (S)
unnamed: R1_BAT.2, U.1 (STAT)
unnamed: GHC_LED.C, R1_BAT.1
unnamed: C_DELAY.1, IC1.5 (CT)
unnamed: R2_BAT.2, U.5 (PROG)
PREVGH: D5.1 (K), EPD_C9.2, J1.21
PREVGL: D4.2 (A), EPD_C11.2, J1.23
RESE: J1.3, Q1.2 (S), R3.2
RESE': R2.2, R3.1, SJ1.2
RESET: C5.1, IC1.1 (VOUT), RESET_BUTTON.3, RESET_BUTTON.4, R_RESET.1, U2.3 (EN)
RTC_RST: U2.16 (IO18), U3.4 (!RST)
RX: TP2.TP, U2.24 (RXD0/GPIO17)
SCK: D10.2, J1.13, J4.P5 (CLK), R6.1, TP8.TP, U1.6 (CLK), U2.6 (IO6)
SCL: J3.4, R2-PINH.1, SENSOR2.4 (SCK), U2.20 (IO22), U3.16 (SCL), U4.7 (SCL)
SDA: J3.3, R1-PINH.1, SENSOR2.3 (SDI), U2.19 (IO21), U3.15 (SDA), U4.8 (SDA)
SRC: C4.2, D5.2 (A), L1.1, Q1.3 (D)
SS_SD: D8.2, J4.P2 (CD/DAT3), R10.1, U2.4 (IO4)
TX: TP1.TP, U2.25 (TXD0/GPIO16)
USB_D+: D1.1 (I/O1_1), U2.14 (IO13)
USB_D-: D1.3 (I/O2_1), U2.13 (IO12)
VBAT: C2_BAT.1, Q3.3 (D), TP3.TP, U.3 (VBAT), U4.2 (CELL), U4.3 (VDD)
VBUS: C1_BAT.1, C4_USB.1, C5_USB.1, D1.5 (VBUS), D2.2 (ANODE), GHC_LED.A, PFMF.050.1.2, Q3.1 (G), R1_PWRUSB.2, TP14.TP, U.4 (VIN)
VRTC: C8.1, C10_SUPERCAP.2, R_CAPACITOR.2, U3.14 (VBAT)
VUSB: J2.A4, J2.A9, J2.B4, J2.B9, PFMF.050.1.1

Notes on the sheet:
USB C connector & ESD protection
LDO Voltage Regulator
SD Card
Display Type Selector
E-Paper Drive Circuit
Li-Po Battery Charging Controller
ESP32 C6
Battery Charge Level
Voltage Supervisor + Reset & Boot / IO Button
Environmental Sensor BME688
EPD Power
E-Paper Display Header
RTC Module DS3231SN
Test Pads
Qwiic / Stemma QT
SPI ESD Protection Lines
External NOR Flash 64MB
SD0805S020S1R0
DMG2305UX-7

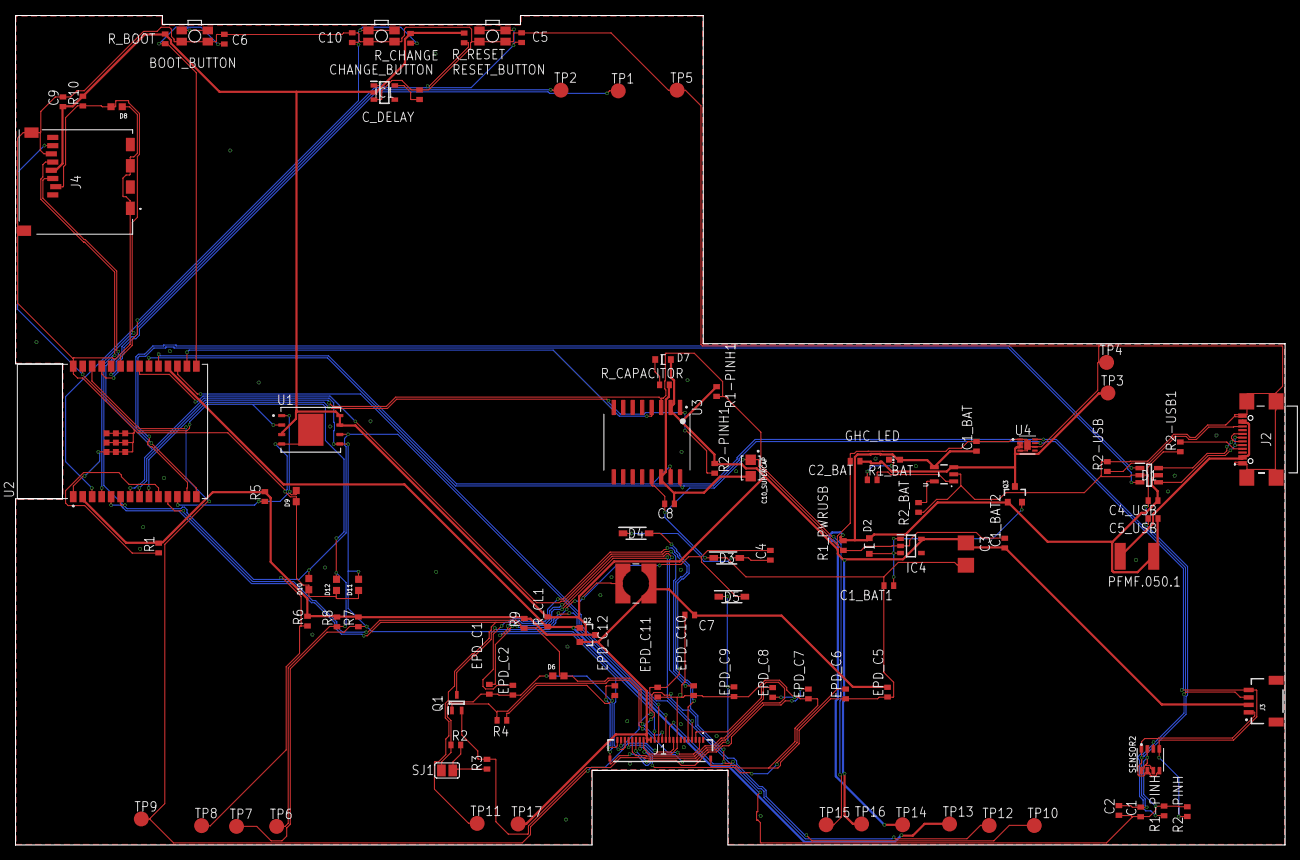
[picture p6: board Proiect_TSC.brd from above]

Board: 2 copper layers, 170.2 x 111.2 mm, 103 parts (0 on the bottom side), 55 nets.

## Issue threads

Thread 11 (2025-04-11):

GND Bottom

RaduRoibu23, 2025-04-11:
Nu ai realizat bine ground-ul pe layer-ul de bottom. Ai o parte mare lipsa de la x = 0 la x = 113

sammsonn, 2025-04-13:
Am acoperit total si layer-ul de top si layer-ul de bottom acum.

Closed 2025-04-13.

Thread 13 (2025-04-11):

Erori acceptate

RaduRoibu23, 2025-04-11:
Ai multe erori pe care le-ai acceptat in loc sa le rezolvi.

Air wire-uri
Ai un overlap de la o piesa.
Ai inca o eroare de over

sammsonn, 2025-04-13:
Am rezolvat toate erorile in afara de cele 2 erori de Board Outline Clearance carora le-am dat approve dupa indicatii.

Closed 2025-04-13.

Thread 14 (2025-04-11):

Quick Route

RaduRoibu23, 2025-04-11:
Cand incerc sa fac Quick Route pe ce ai tu nu imi da 100% la niciuna. Incearca sa vezi dupa ce corectezi erorile poate iti da.

Nu cred ca era obligatoriu sa fie 100%, dar am zis sa fac o remarca pe treaba asta.

sammsonn, 2025-04-13:
Cand dai Auto Route nu ajunge la 100%, raman 3 erori de airwire, dar le-am rutat manual si e totul in regula.

Closed 2025-04-13.

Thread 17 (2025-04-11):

README Issues

RaduRoibu23, 2025-04-11:
Probleme cu BOM (Bill Of Materials):

Unele link-uri din coloana Check_Price nu sunt de la Mouser/Comet conform cerintelor
Unele link-uri catre datasheet-uri sunt defecte sau inaccesibile
Exemplu: Link-ul pentru "ADAFRUIT_LEDCHIP-LED0603" trimite catre snapeda.com in loc de Mouser/Comet

Probleme cu Descrierea Functionalitatii Hardware:

Lipsesc calculele detaliate ale consumului de energie pentru diferite moduri de functionare
Nu exista o explicatie clara a retelei de distributie a puterii
Nu exista informatii despre structura PCB-ului si utilizarea straturilor
Lipsesc informatiile despre managementul termic
Nu exista documentatie clara a protocoalelor de comunicare utilizate
Lipsesc diagramele de timing
Nu exista informatii despre considerentele de integritate a semnalului|

Probleme cu Sectiunea "Probleme Intampinate"

Am intampinat niste erori care nu erau mentionate in README. erori pe care le-am semnalat in alt issue.

Probleme cu Sectiunea "Descriere Generala"

Trebuia sa fie mai ampla putin, sa deteliezi oleaca ce ai facut in fiecare etapa.

sammsonn, 2025-04-13:
Probleme cu BOM (Bill Of Materials):

Link-urile din coloana check_price pot fi si din alte surse, aia era doar o recomandare, eu am pus exact de unde am luat fiecare piesa.
Am verificat toate link-urile din BOM si merg normal. Era un link lipsa la un datasheet dar l-am adaugat.

Probleme cu Descrierea Functionalitatii Hardware:

Consumul de energie se afla in tabelul "Profil de Consum Energetic".
Te rog sa clarifici mai exact la ce te referi prin reteaua de distributie a puterii.
Structura PCB-ului si utilizarea straturilor se poate observa usor din fisierul .brd.
Managementul termic poate fi adaugat intr-o etapa viitoare a proiectului.
Documentatia pentru protocoalele de comunicare utilizate se afla in tabelul "Protocoale de Comunicare si Interfete Utilizate".
Diagramele de timing nu fac parte din aceasta documentatie.
Din nou, te rog sa clarifici mai exact la ce te referi prin considerentele de integritate a semnalului.

Probleme cu Sectiunea "Probleme Intampinate":

Am rezolvat toate erorile mentionate in celelalte issue-uri.

Probleme cu Sectiunea "Descriere Generala":

Am detaliat mai mult ce am facut in fiecare etapa a proiectului.

Closed 2025-04-13.

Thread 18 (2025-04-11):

README

RaduRoibu23, 2025-04-11:
Probleme cu BOM (Bill Of Materials):

Unele link-uri din coloana Check_Price nu sunt de la Mouser/Comet conform cerintelor
Unele link-uri catre datasheet-uri sunt defecte sau inaccesibile
Exemplu: Link-ul pentru "ADAFRUIT_LEDCHIP-LED0603" trimite catre snapeda.com in loc de Mouser/Comet

Probleme cu Descrierea Functionalitatii Hardware:

Lipsesc calculele detaliate ale consumului de energie pentru diferite moduri de functionare
Nu exista o explicatie clara a retelei de distributie a puterii
Nu exista informatii despre structura PCB-ului si utilizarea straturilor
Lipsesc informatiile despre managementul termic
Nu exista documentatie clara a protocoalelor de comunicare utilizate
Lipsesc diagramele de timing
Nu exista informatii despre considerentele de integritate a semnalului|

Probleme cu Sectiunea "Probleme Intampinate"

Am intampinat niste erori care nu erau mentionate in README. erori pe care le-am semnalat in alt issue.

Probleme cu Sectiunea "Descriere Generala"

Trebuia sa fie mai ampla putin, sa deteliezi oleaca ce ai facut in fiecare etapa.

Closed 2025-04-11.

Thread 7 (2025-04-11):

E-Paper Drive Circuit Denumiri Componente

RaduRoibu23, 2025-04-11:
Denumirile componentelor difera fata de cele din schematic. D3 != D4 etc...

sammsonn, 2025-04-12:
Denumirile componentelor sunt corecte, posibil ca ai facut o confuzie din cauza pozitiei denumirilor. Am schimbat pozitia denumirilor ca sa fie la fel ca in schematic-ul original.

Closed 2025-04-12.

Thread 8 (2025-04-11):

E-Paper Display Header Aspect + bug

RaduRoibu23, 2025-04-11:
Textul trebuie aranjat mai bine , nu se intelge mai nimic din el. Erau 2 piese la fel cu o mica diferenta intre ele. Nu stiu daca e un bug vizual la mine sau nu , dar iti lipseste scrisul de la capacitoare. Verifica schema.

sammsonn, 2025-04-12:
Cred ca era un bug, scrisul de la capacitoare e acolo dar era rotit si inghesuit. Am modificat aspectul lor si acum ar trebui sa fie ok.

Closed 2025-04-12.

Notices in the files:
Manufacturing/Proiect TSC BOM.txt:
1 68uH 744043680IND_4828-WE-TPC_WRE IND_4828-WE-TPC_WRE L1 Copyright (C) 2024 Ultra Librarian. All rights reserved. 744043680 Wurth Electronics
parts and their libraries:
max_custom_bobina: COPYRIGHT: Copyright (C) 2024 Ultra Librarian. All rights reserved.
